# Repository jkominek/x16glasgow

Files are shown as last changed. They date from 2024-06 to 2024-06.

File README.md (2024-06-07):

# Commander X16 to Glasgow adapter

This is an expansion card for the [Commander
X16](https://x16community.github.io/faq/faq.html) retro PC, which
exposes one memory mapped IO region (at a time) to a [Glasgow
Interface Explorer](https://glasgow-embedded.org/latest/intro.html).

With it, the Glasgow can emulate nearly any IO card you might plug
into the X16, so long as that card only wants to talk to a modern
USB-capable PC 🤓. So far I've [got an
applet](https://github.com/jkominek/glasgow) which half-assedly
emulates a 16550, and hooks it up to a pseudoterminal on a Linux
system. With David Murray's ROMTERM, you can then use the X16 as
a "serial" terminal to log into the Linux system.

(To be super clear, that's all done without the [Commander X16 Serial
& ESP32 Network
card](https://texelec.com/product/commander-x16-serial-network-card/).)

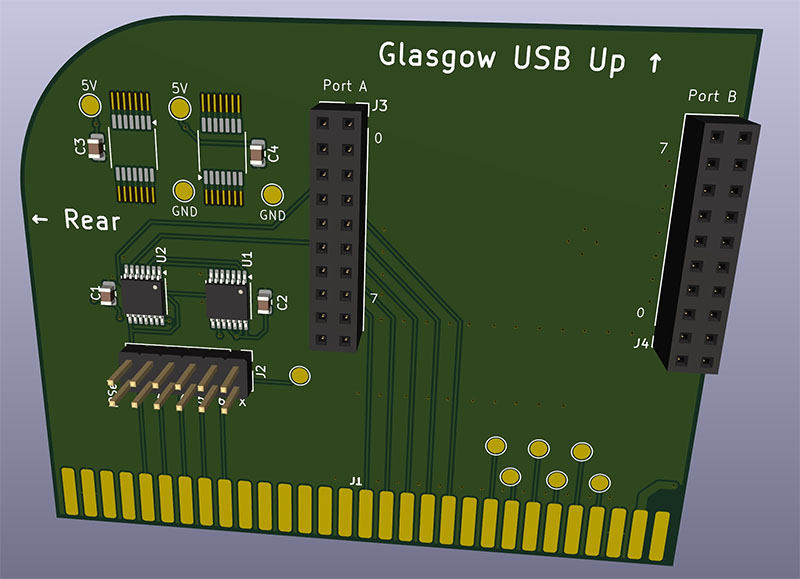
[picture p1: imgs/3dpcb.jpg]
KiCad render of the card


And here's a quick little video of it in operation: https://www.youtube.com/watch?v=3OkkUSMPfc0

# how it works

The Glasgow has 16 IO pins. To act as an IO device, you need to handle:
- 8 data lines
- RWB
- PHI2
- At least one of the IO selection lines
- An IRQ
- Five address lines (for the full 32 byte space)

That's 17 lines. You could drop the IRQ line, but that'd be boring.
Instead, we decode RWB, PHI2 and a jumper-chosen IO selection line
using some 74-series logic, and condense the three of them into
/RD and /WR lines. That fits everything into 16 pins.

# how do i get a getty on a pseudoterminal

```
mgetty -r -b -m '""' /dev/pts/X
```

not actually sure if the `-b` is necessary. The `-m` bit was the secret
sauce.

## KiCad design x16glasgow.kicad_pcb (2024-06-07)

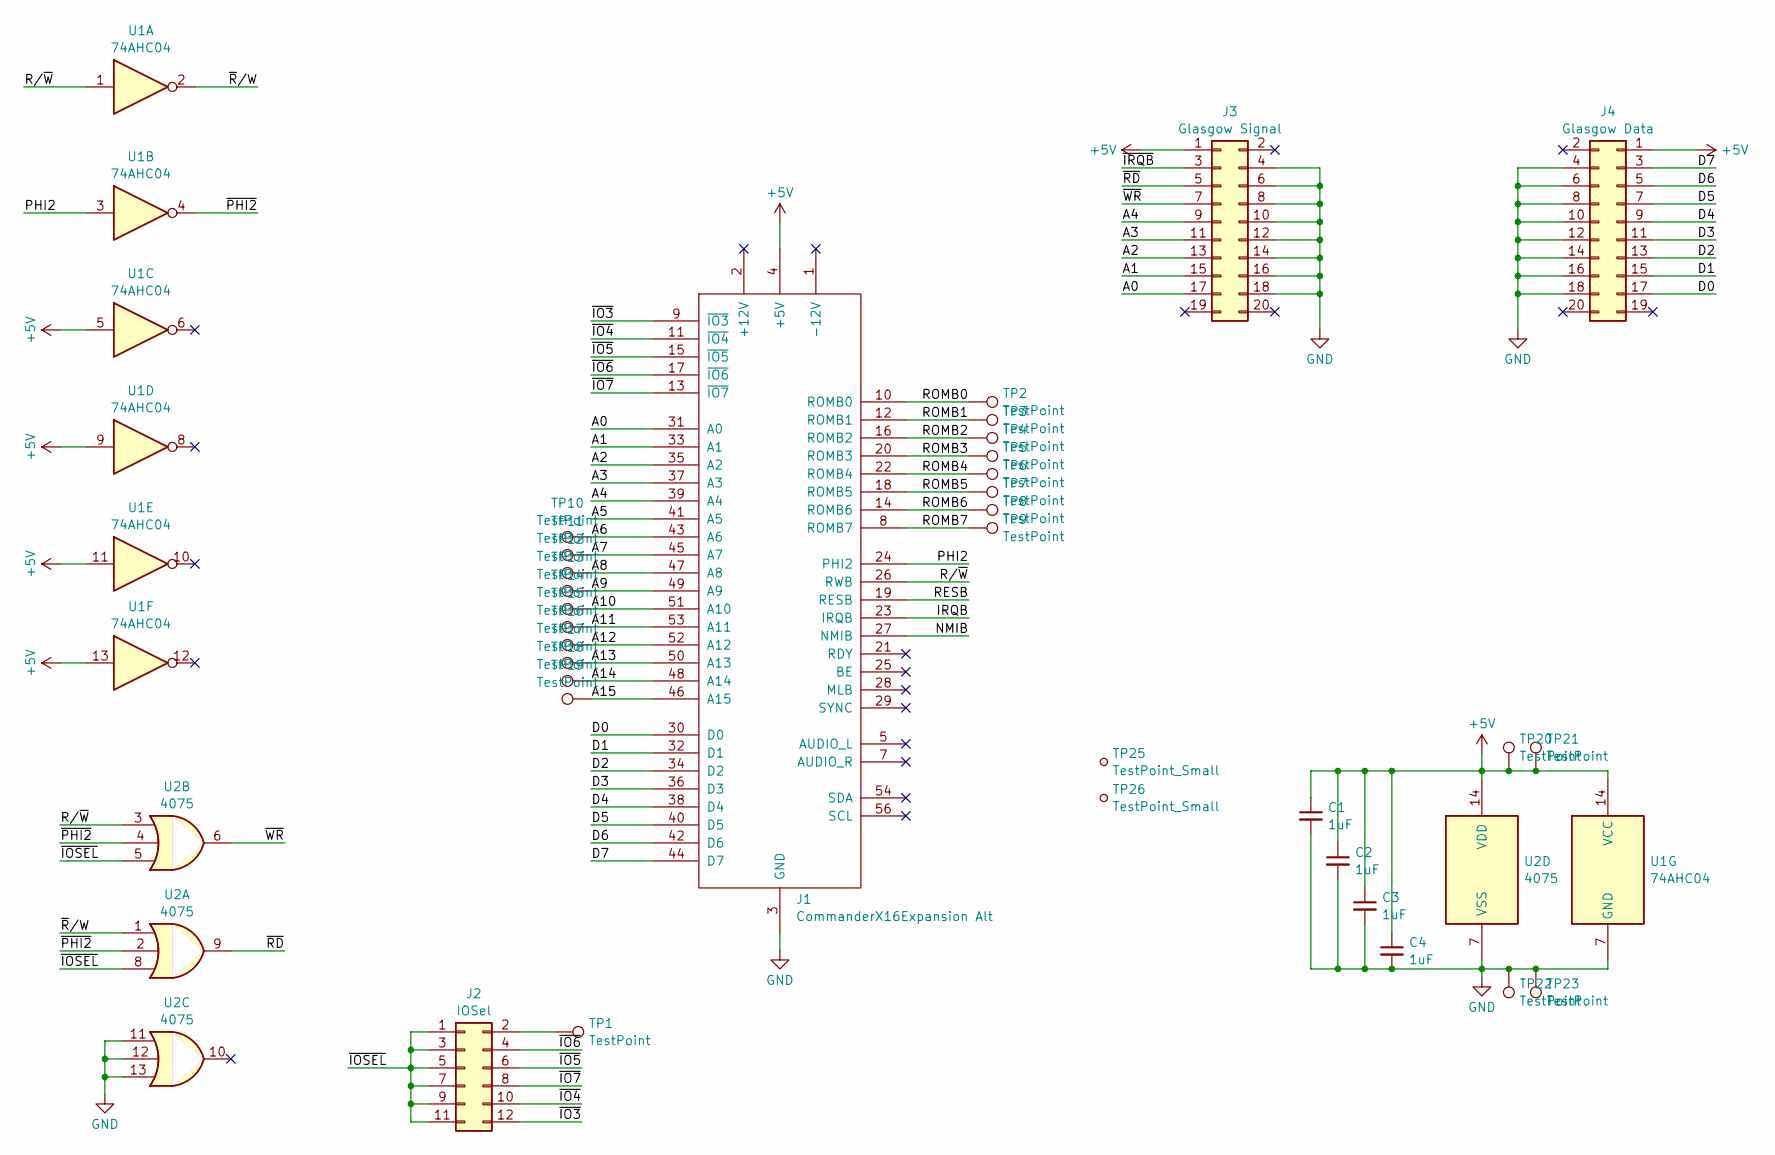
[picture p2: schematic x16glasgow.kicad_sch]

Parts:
C1, C2, C3, C4: 1uF; C_0805_2012Metric
J1: CommanderX16Expansion Alt; CommanderX16Expansion
J2: IOSel; PinHeader_2x06_P2.54mm_Vertical
J3: Glasgow Signal; PinSocket_2x10_P2.54mm_Vertical
J4: Glasgow Data; PinSocket_2x10_P2.54mm_Vertical
TP1, TP2, TP3, TP4, TP5, TP6, TP7, TP8, TP9, TP10, TP11, TP12, TP13, TP14, TP15, TP16, TP17, TP18, TP19, TP20, TP21, TP22, TP23: TestPoint; TestPoint_Pad_D2.0mm
TP25, TP26: TestPoint_Small; TSSOP-14_4.4x5mm_P0.65mm
U1: 74AHC04; TSSOP-14_4.4x5mm_P0.65mm
U2: 4075; TSSOP-14_4.4x5mm_P0.65mm

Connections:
+5V: C1.1, C2.1, C3.1, C4.1, J1.4 (+5V), J1.57 (+5V), J3.1, J4.1, TP20.1, TP21.1, U1.5, U1.9, U1.11, U1.13, U1.14 (VCC), U2.14 (VDD)
/A0: J1.31 (A0), J3.17
/A1: J1.33 (A1), J3.15
/A2: J1.35 (A2), J3.13
/A3: J1.37 (A3), J3.11
/A4: J1.39 (A4), J3.9
/A5: J1.41 (A5)
/A6: J1.43 (A6), TP10.1
/A7: J1.45 (A7), TP11.1
/A8: J1.47 (A8), TP12.1
/A9: J1.49 (A9), TP13.1
/A10: J1.51 (A10), TP14.1
/A11: J1.53 (A11), TP15.1
/A12: J1.52 (A12), TP16.1
/A13: J1.50 (A13), TP17.1
/A14: J1.48 (A14), TP18.1
/A15: J1.46 (A15), TP19.1
/D0: J1.30 (D0), J4.17
/D1: J1.32 (D1), J4.15
/D2: J1.34 (D2), J4.13
/D3: J1.36 (D3), J4.11
/D4: J1.38 (D4), J4.9
/D5: J1.40 (D5), J4.7
/D6: J1.42 (D6), J4.5
/D7: J1.44 (D7), J4.3
/IRQB: J1.23 (IRQB)
/NMIB: J1.27 (NMIB)
/PHI2: J1.24 (PHI2), U1.3
/RESB: J1.19 (RESB)
/ROMB0: J1.10 (ROMB0), TP2.1
/ROMB1: J1.12 (ROMB1), TP3.1
/ROMB2: J1.16 (ROMB2), TP4.1
/ROMB3: J1.20 (ROMB3), TP5.1
/ROMB4: J1.22 (ROMB4), TP6.1
/ROMB5: J1.18 (ROMB5), TP7.1
/ROMB6: J1.14 (ROMB6), TP8.1
/ROMB7: J1.8 (ROMB7), TP9.1
/R/~W: J1.26 (RWB), U1.1, U2.3
/~IO3: J1.9 (~IO3), J2.12
/~IO4: J1.11 (~IO4), J2.10
/~IO5: J1.15 (~IO5), J2.6
/~IO6: J1.17 (~IO6), J2.4
/~IO7: J1.13 (~IO7), J2.8
/~IOSEL: J2.1, J2.3, J2.5, J2.7, J2.9, J2.11, U2.5, U2.8
/~IRQB: J3.3
/~PHI2: U1.4, U2.2, U2.4
/~RD: J3.5, U2.9
/~R/W: U1.2, U2.1
/~WR: J3.7, U2.6
GND: C1.2, C2.2, C3.2, C4.2, J1.3 (GND), J1.6 (GND), J1.55 (GND), J1.58 (GND), J3.4, J3.6, J3.8, J3.10, J3.12, J3.14, J3.16, J3.18, J4.4, J4.6, J4.8, J4.10, J4.12, J4.14, J4.16, J4.18, TP22.1, TP23.1, U1.7 (GND), U2.7 (VSS), U2.11, U2.12, U2.13
unnamed: J2.2, TP1.1

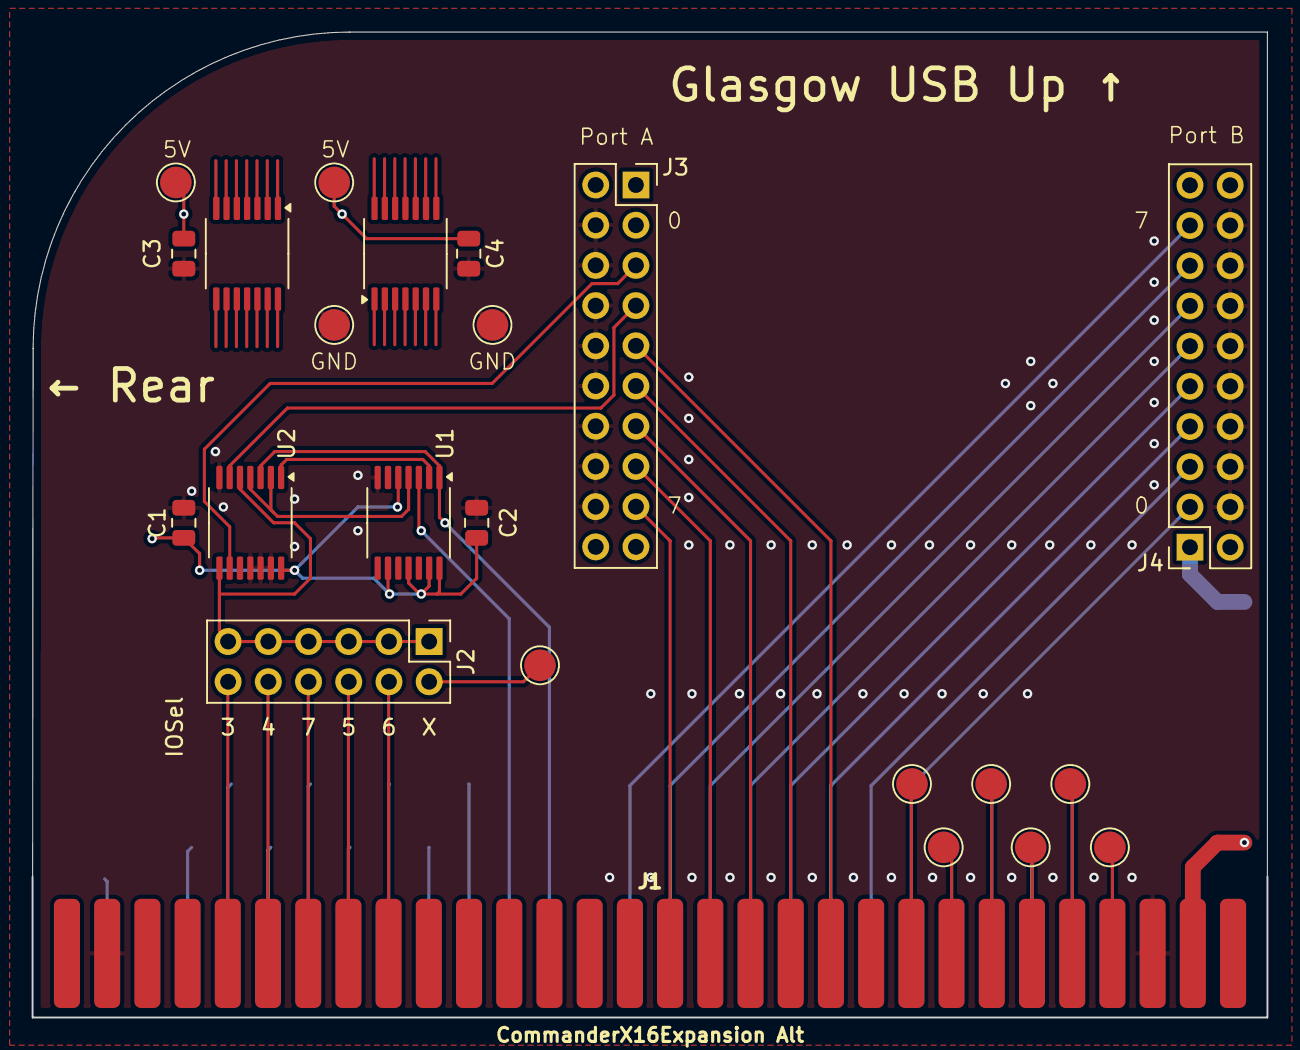
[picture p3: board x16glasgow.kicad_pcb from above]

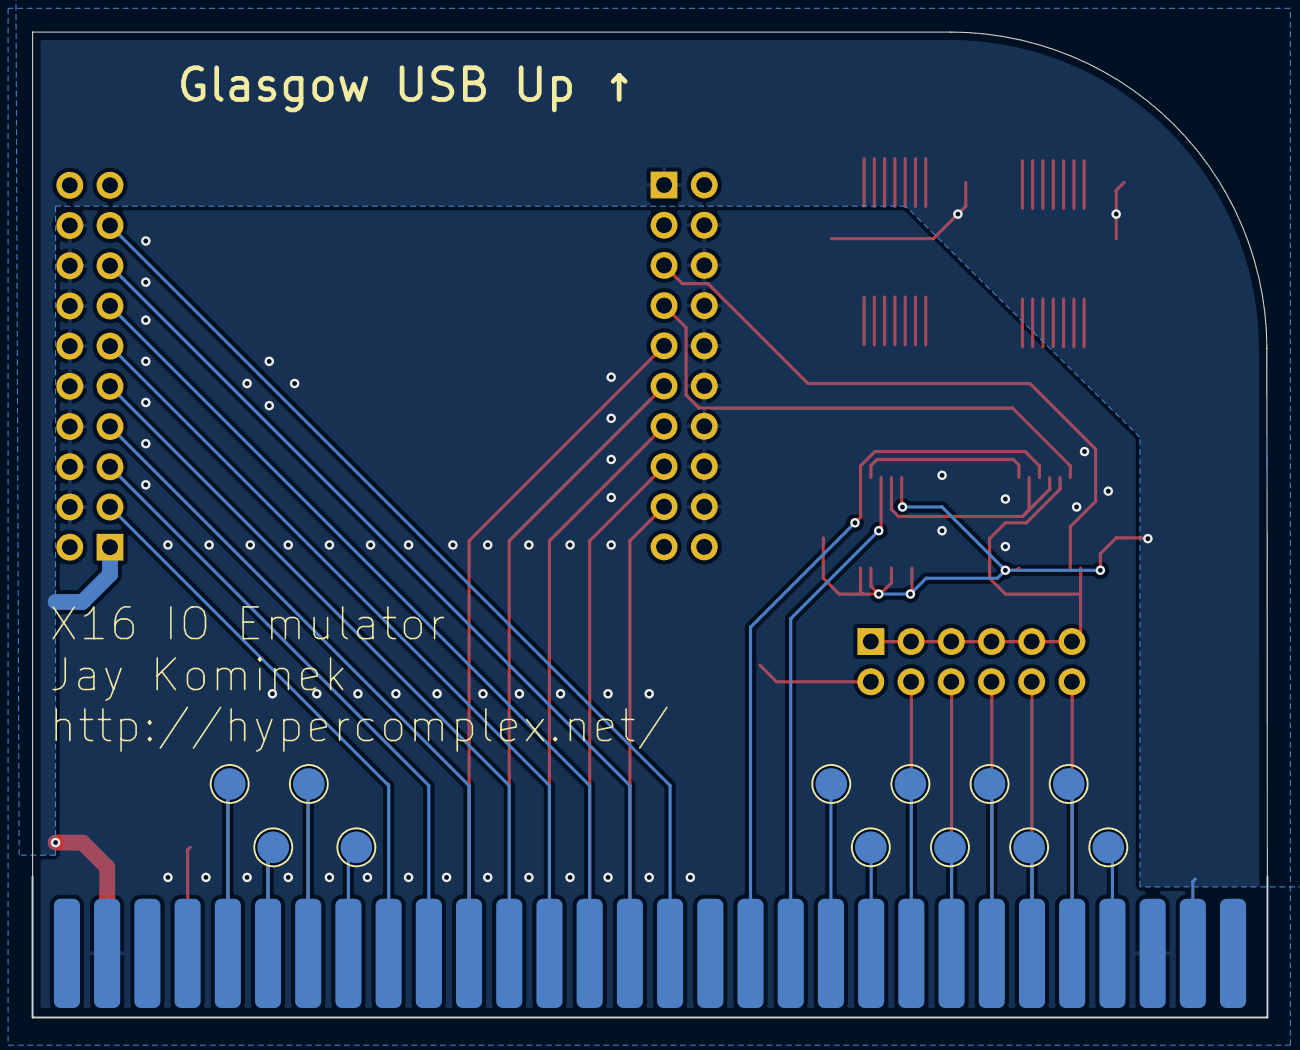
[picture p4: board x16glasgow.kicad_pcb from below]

Board: 2 copper layers, 78.0 x 62.2 mm, 35 parts (12 on the bottom side), 46 nets.
